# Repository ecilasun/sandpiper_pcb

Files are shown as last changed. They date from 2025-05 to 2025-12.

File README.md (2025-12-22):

## Sandpiper keyboard PCB and enclosure design files

This repo contains the PCB files for sandpiper project.

## Notes

- This PCB is optional and is not required to be able to run sandpiper. It merely contains a custom USB keyboard that fits into the provided enclosure.
- The enclosure is also optional. Sandpiper does not requre an enclosure to function and can be booted from pretty much any Xynq7020 board with 512Mbytes of memory, an etnernet and USB controller, plus some HDMI connector leading to the FPGA pins. For boards with more memory than 512Mbytes the device tree and SDK has to be updated to shift device addresses to the last 32Mbytes of memory. This also means th driver has to be rebuilt with those addresses (in the future driver will read them from the devic tree so there won't be a need to rebuild it)
- The enclosure is designed to be printed in one big piece for the top and bottom halves (plus the side connection pieces) Recommended material is PETG-strong as it is very unlikely to warp. Other materials might also work but print at your own risk or split the design manually, as there's no built-in measures in the design to avoid warping.
- Enclosure design requires solidworks connected, and the pcb design required KiCad 9 or above.
- If you intend to build a PCB yourself via online services (oshpark, jlcpcb etc) please note to match the parts to the ones listed as close as you can. Mismatches in part numbers might result in wrong pin connections.
- If you build the keyboard PCB and want to program the firmware on it, please see the firmware/ folder in this repo. Use an AVR programmer with AVRdude / AVRdudess or QMK Toolbox to burn the flash onto the chip.
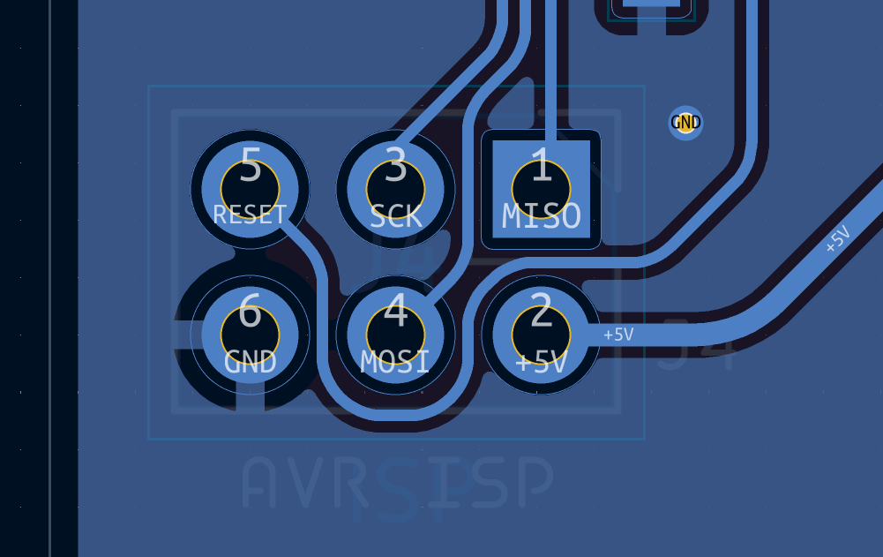
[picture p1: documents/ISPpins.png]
- The pin header for the programmer goes on the bottom side of the board where the chip sits, and the square pin connection is actually the MISO pin and not the ground pin due to an error. Please see the following image to locate the correct pins and plug the programmer header accordingly:<br><br>
- Do not forget to cut or remove the programming header pins once you're done so that the board does not get stuck or bend when sliding it into the rails on the bottom side of the enclosure.

## Documentation

See the [Sandpiper project page](https://ecilasun.github.io/sandpiper/) for links to all related repositories and SDK documentation.

## Development toolchains

See the [Sandpiper project page](https://ecilasun.github.io/sandpiper/) for development toolchain setup instructions.

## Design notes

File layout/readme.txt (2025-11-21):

Please open the attached sandpiper-layout.json file in https://www.keyboard-layout-editor.com/#/ (drag+drop it)

Now download the layout and paste it into the following web site and check that the wiring is correct
https://kbfirmware.com/

(Or if you're in a hurry, I've already provided a premade layout json file here: sandpiperfirmwarelayout.json that you can Upload)

Now you can use the Compile section to generate the firmware to upload to the microcontroller

NOTE: In case of an issue and if the import doesn't work, try to paste the following into the Raw Data tab:

["ESC","!\n1","@\n2","#\n3","$\n4","%\n5","^\n6","&\n7","*\n8","(\n9",")\n0","_\n-","+\n=",{w:2},"Backspace"],
[{w:1.5},"Tab","Q","W","E","R","T","Y","U","I","O","P","{\n[","}\n]",{w:1.5},"|\n\\"],
[{w:1.75},"Caps Lock","A","S","D","F","G","H","J","K","L",":\n;","\"\n'",{w:2.25},"Enter"],
[{x:0.5,w:1.75},"Shift","Z","X","C","V","B","N","M","<\n,",">\n.","?\n/",{w:2.25},"Shift","↑"],
[{x:0.5,w:1.25},"Ctrl","Fn",{w:1.25},"Alt",{x:0.25,a:7,w:6.25},"",{x:0.25,a:4,w:1.25},"Alt","Pause",{x:0.5},"←","↓","→"]

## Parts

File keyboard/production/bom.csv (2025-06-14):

Designator | Footprint | Quantity | Value | LCSC Part #
C1 | 0805 | 1 | 1uF
C2, C3, C4 | 0805 | 3 | 0.1uF
C5 | 0805 | 1 | 10uF
C6, C7 | 0805 | 2 | 22pF
C8 | 0805 | 1 | 100nF
D1, D10, D11, D12, D13, D14, D15, D16, D17, D18, D19, D2, D20, D21, D22, D23, D24, D25, D26, D27, D28, D29, D3, D30, D31, D32, D33, D34, D35, D36, D37, D38, D39, D4, D40, D41, D42, D43, D44, D45, D46, D47, D48, D49, D5, D50, D51, D52, D53, D54, D55, D56, D57, D58, D59, D6, D60, D61, D62, D63, D7, D8, D9 | D_SOD-323_HandSoldering | 63 | 1N4148WS‎
R1, R4 | 0805 | 2 | 10K
R2, R3 | 0805 | 2 | 22R
U1 | TQFP-44_10x10mm_P0.8mm | 1 | ATmega32U4-A
Y1 | Crystal_SMD_3225-4Pin_3.2x2.5mm | 1 | 16MHz

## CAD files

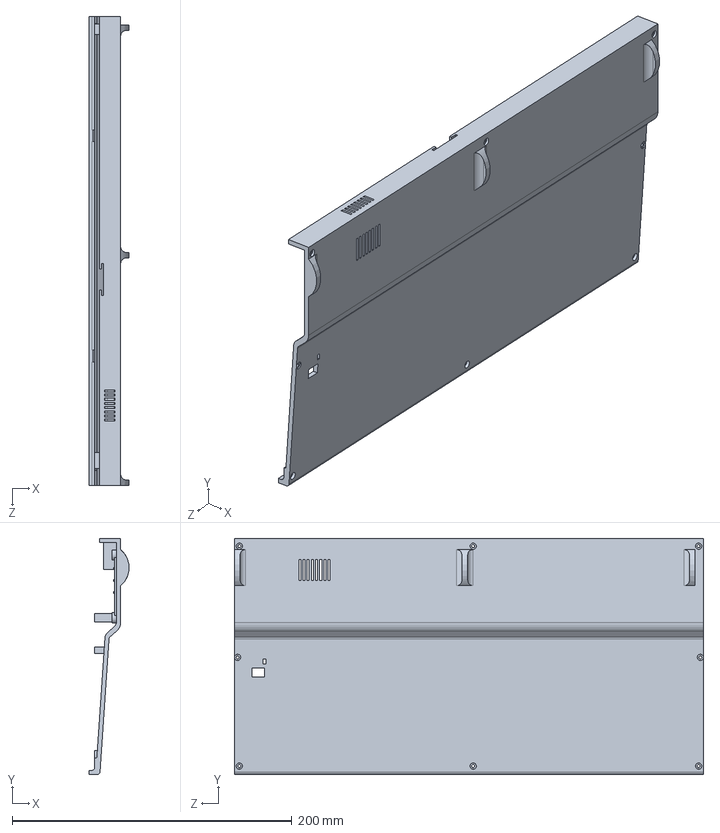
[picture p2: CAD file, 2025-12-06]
enclosure/profile.SLDPRT
28.6 x 168.8 x 335.5 mm

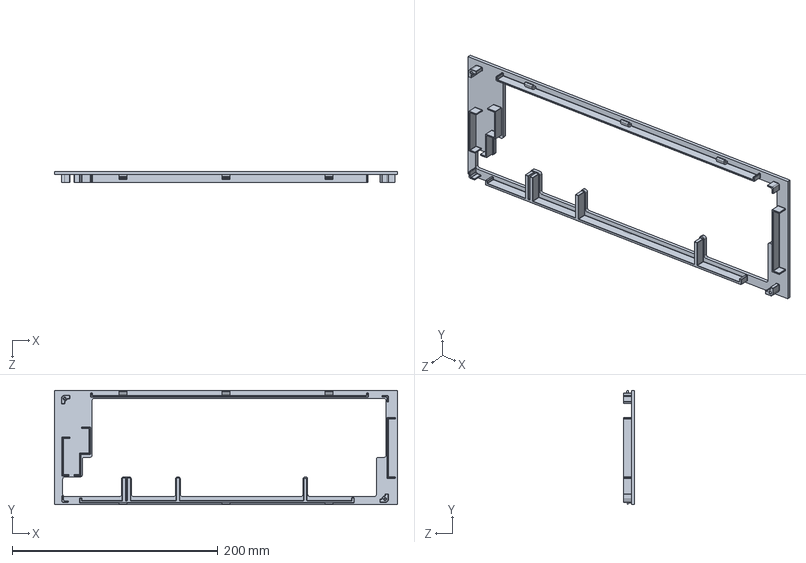
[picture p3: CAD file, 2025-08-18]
enclosure2/faceplate.SLDPRT
333.4 x 111.2 x 11.1 mm

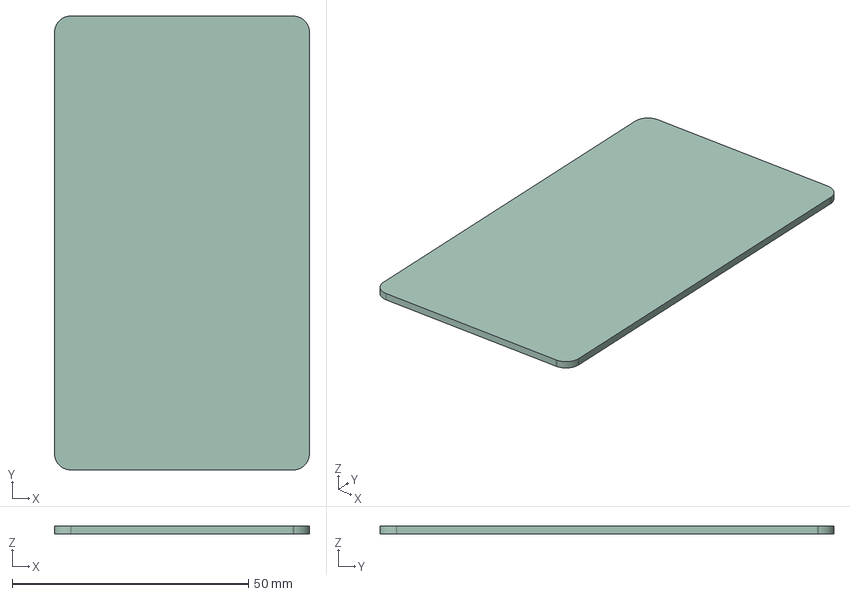
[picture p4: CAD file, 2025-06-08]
fpgamock/fpgamock.step
54.0 x 96.1 x 1.60 mm

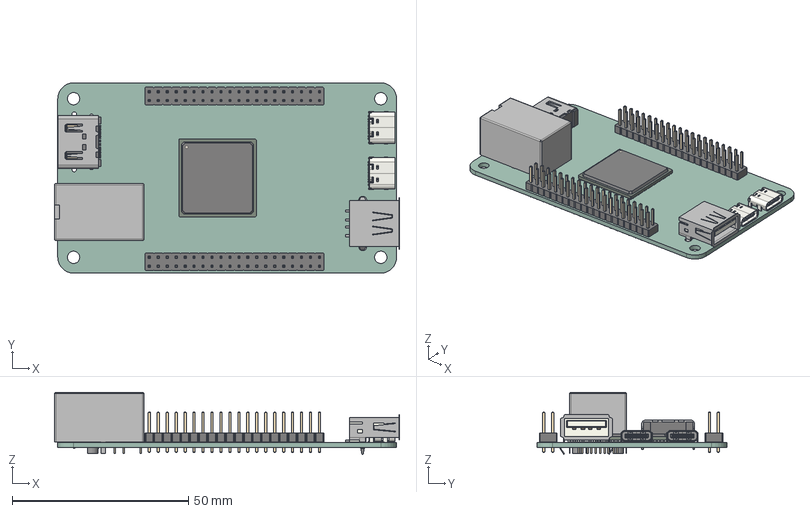
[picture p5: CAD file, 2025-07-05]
keyboard/smartzynqmock.step
97.9 x 54.0 x 17.7 mm
USB_C_Receptacle_GCT_USB4105-xx-A_16P_TopMnt_Horizontal x 2
BGA-484_23.0x23.0mm_Layout22x22_P1.0mm
HDMI_A_Molex_208658-1001_Horizontal
PinHeader_2x20_P2.54mm_Vertical x 2
USB_A_TE_292303-7_Horizontal
RJ45_Molex_9346520x_Horizontal
smartzynqmock_PCB

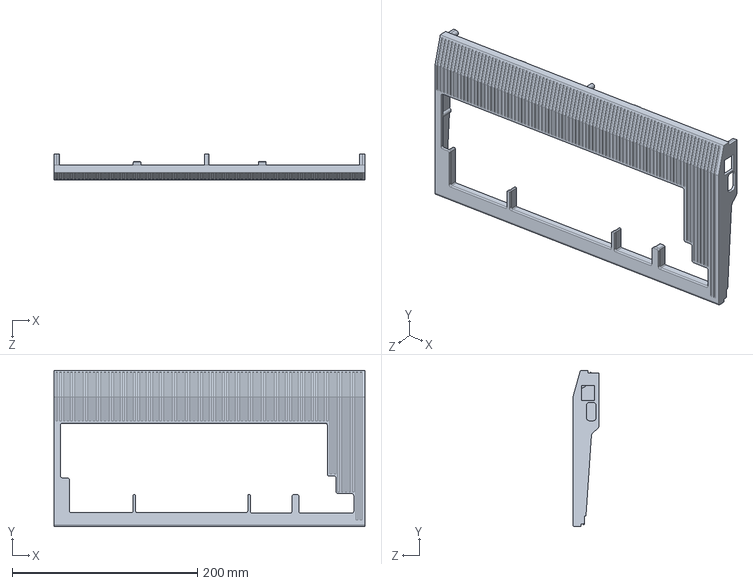
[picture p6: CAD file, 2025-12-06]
enclosure/faceplate.SLDPRT
335.5 x 168.8 x 28.2 mm

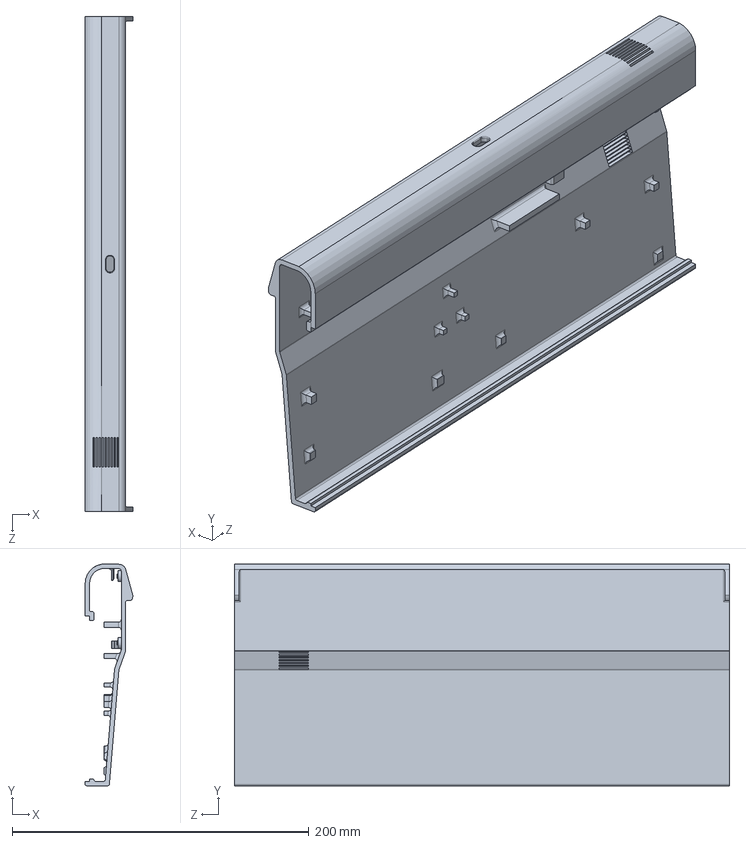
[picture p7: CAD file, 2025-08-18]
enclosure2/bottom.SLDPRT
32.2 x 149.2 x 333.4 mm

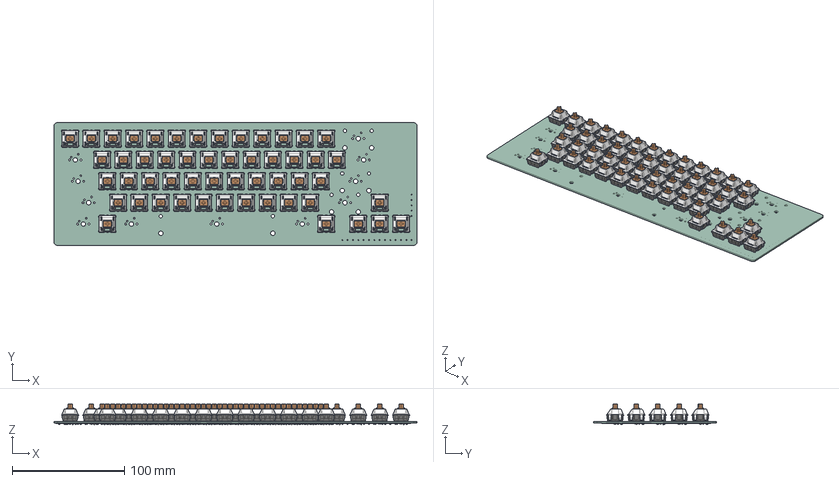
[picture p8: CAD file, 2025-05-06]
keyboard/keyboard.step
323.9 x 109.5 x 18.6 mm
SW_Cherry_MX_PCB_cp x 52
D_SOD_323 x 63
keyboard_PCB

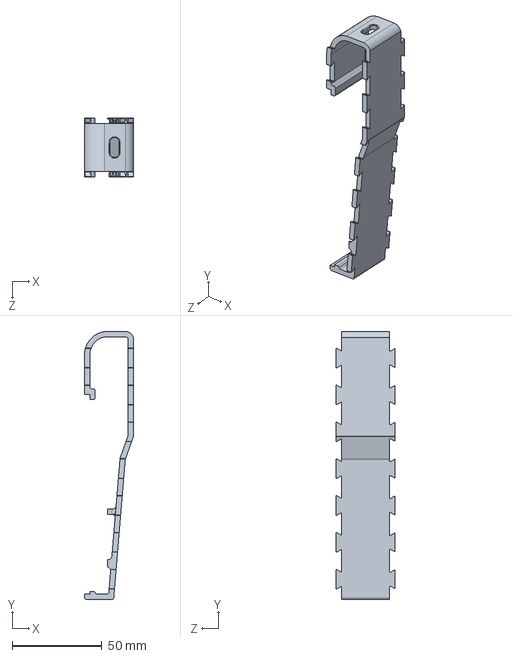
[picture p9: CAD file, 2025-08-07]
enclosure2/bottomcenter.SLDPRT
27.3 x 149.2 x 32.7 mm

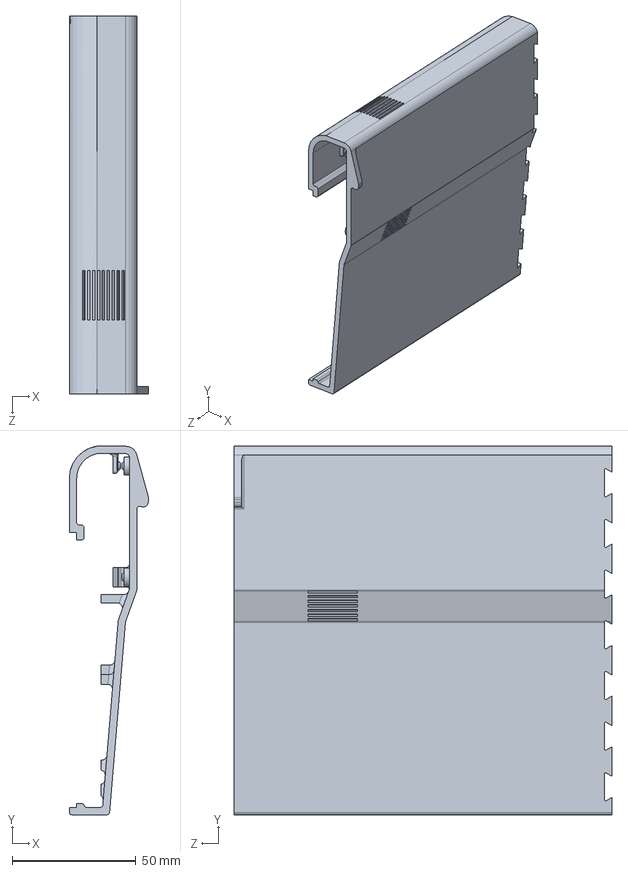
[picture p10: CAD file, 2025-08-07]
enclosure2/bottomright.SLDPRT
32.2 x 149.2 x 153.0 mm

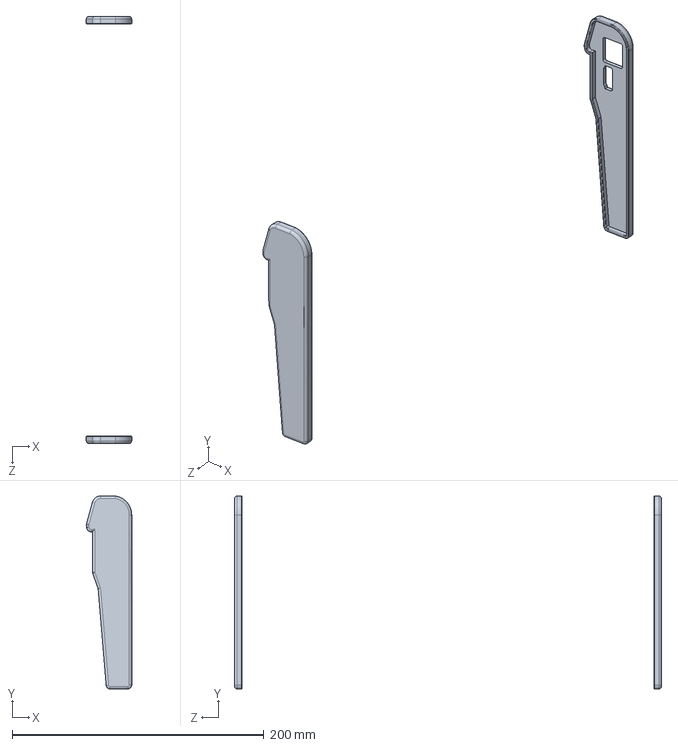
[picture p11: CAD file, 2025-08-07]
enclosure2/sidecovers.SLDPRT
36.1 x 153.2 x 339.1 mm

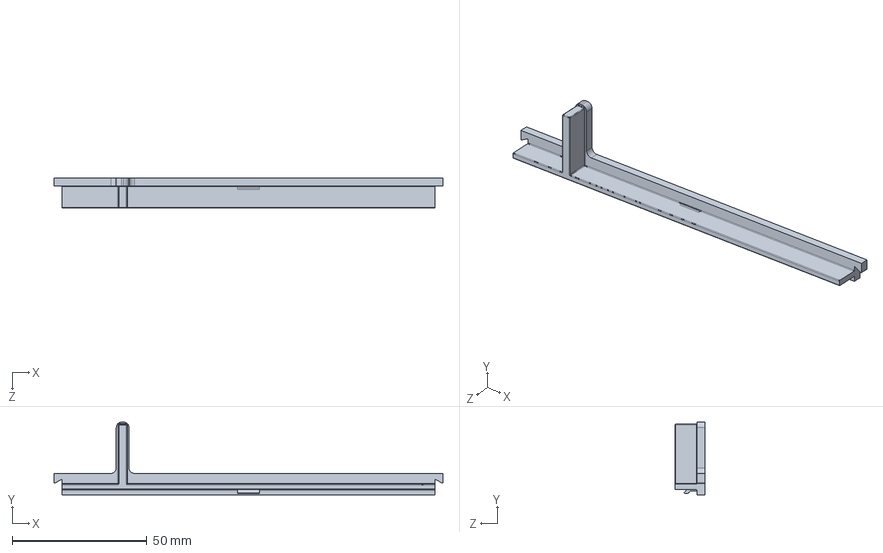
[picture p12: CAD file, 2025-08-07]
enclosure2/platemidbottom.SLDPRT
144.5 x 27.1 x 11.1 mm

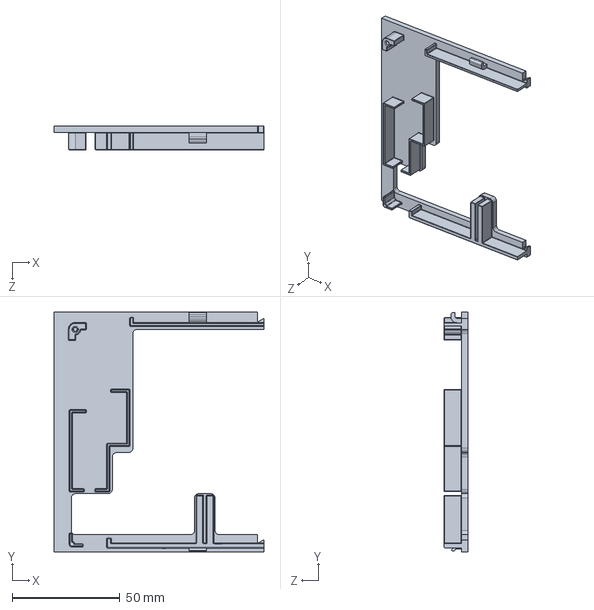
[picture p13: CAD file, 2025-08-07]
enclosure2/plateright.SLDPRT
97.3 x 111.2 x 11.1 mm

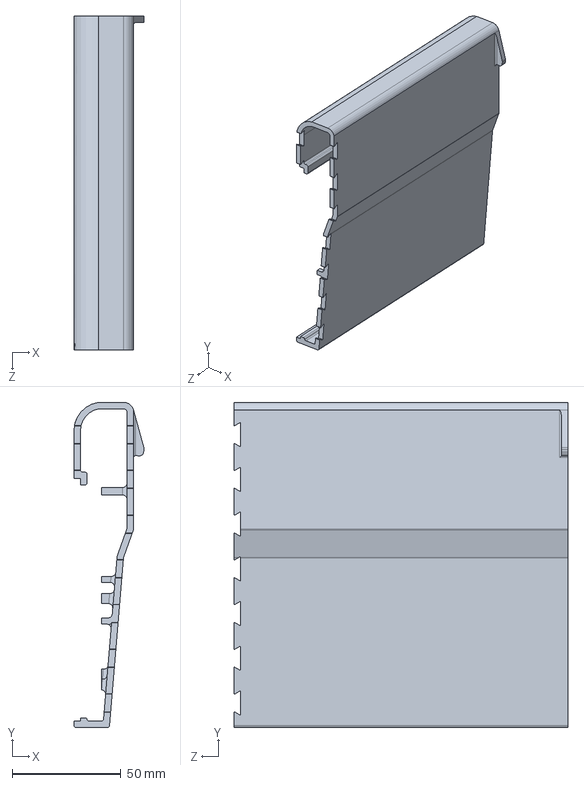
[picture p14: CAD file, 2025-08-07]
enclosure2/bottomleft.SLDPRT
32.2 x 149.2 x 153.2 mm

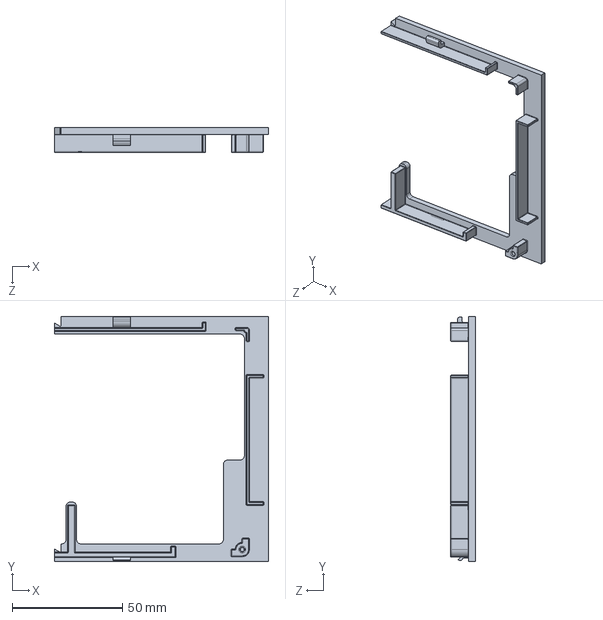
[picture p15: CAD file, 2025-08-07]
enclosure2/plateleft.SLDPRT
97.3 x 111.2 x 11.1 mm

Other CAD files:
keyboard/enclosure/enclosure.SLDASM
enclosure/enclosure.SLDASM
enclosure2/leftbody.SLDPRT
enclosure2/platemidtop.SLDPRT
deprecated/leftbody.SLDPRT
deprecated/platemidtop.SLDPRT
deprecated/platerightSLDPRT.SLDPRT
deprecated/rightbody.SLDPRT
enclosure2/platerightSLDPRT.SLDPRT
enclosure2/rightbody.SLDPRT

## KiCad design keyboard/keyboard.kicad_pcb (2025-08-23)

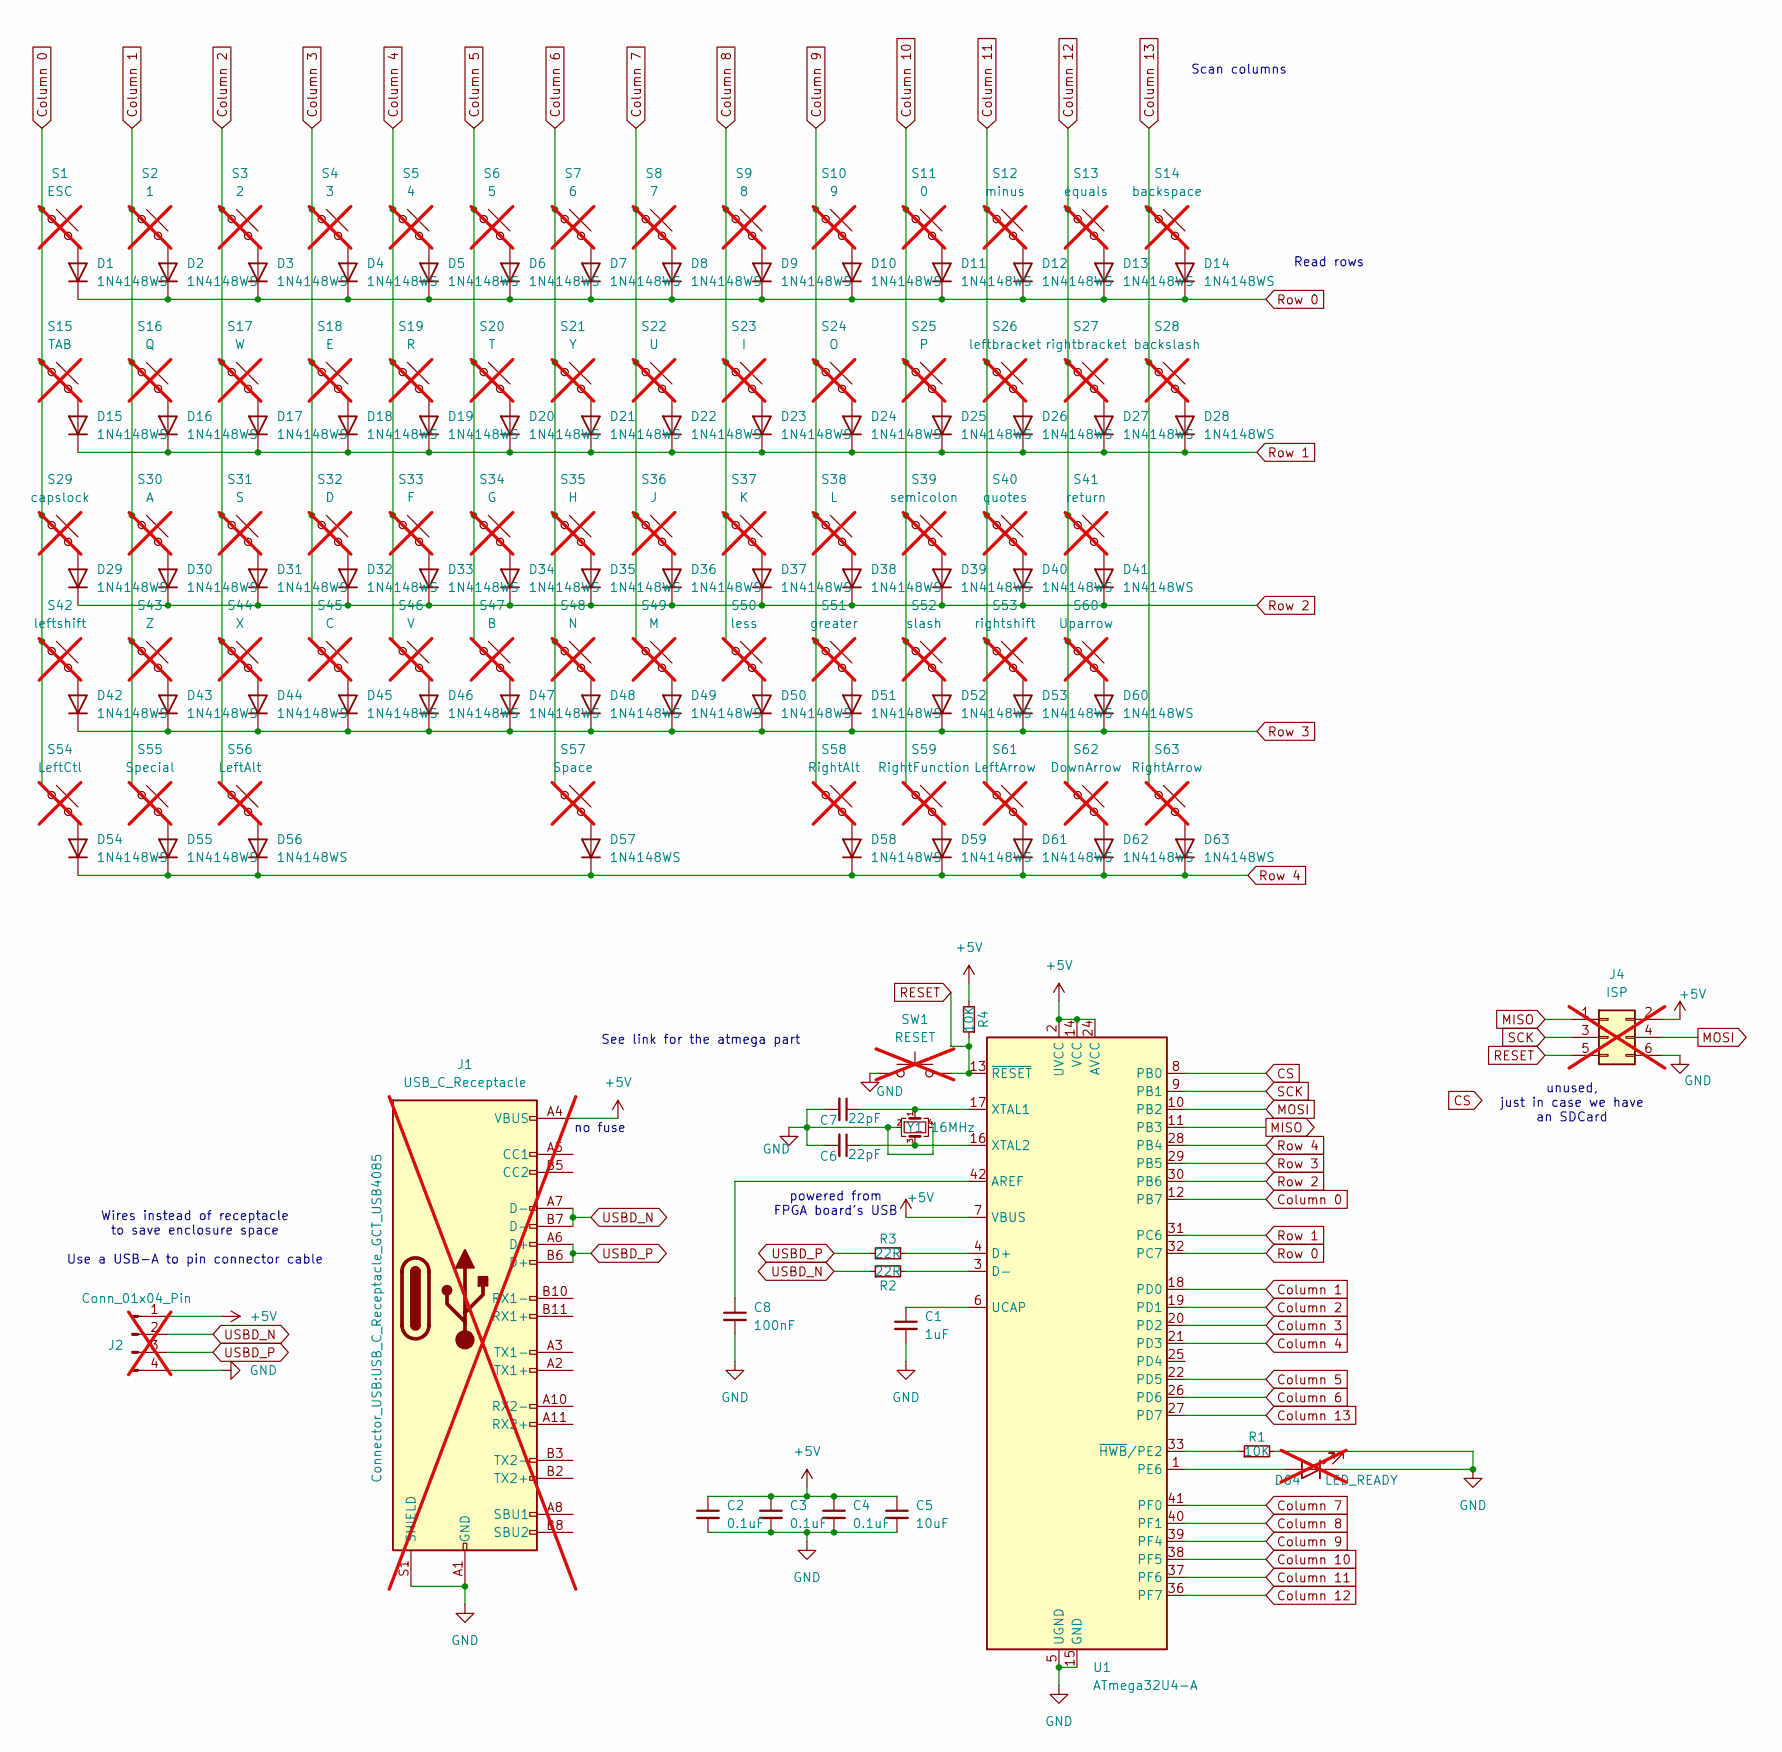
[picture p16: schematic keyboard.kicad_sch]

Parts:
C1: 1uF; C_0805_2012Metric
C2, C3, C4: 0.1uF; C_0805_2012Metric
C5: 10uF; C_0805_2012Metric
C6, C7: 22pF; C_0805_2012Metric
C8: 100nF; C_0805_2012Metric
D1, D2, D3, D4, D5, D6, D7, D8, D9, D10, D11, D12, D13, D14, D15, D16, D17, D18, D19, D20, D21, D22, D23, D24, D25, D26, D27, D28, D29, D30, D31, D32, D33, D34, D35, D36, D37, D38, D39, D40, D41, D42, D43, D44, D45, D46, D47, D48, D49, D50, D51, D52, D53, D54, D55, D56, D57, D58, D59, D60, D61, D62, D63: 1N4148WS‎; D_SOD-323_HandSoldering
D64: LED_READY; LED_1206_3216Metric; not fitted
J1: USB_C_Receptacle; USB_C_Receptacle_GCT_USB4085; not fitted
J2: Conn_01x04_Pin; PinHeader_1x04_P2.54mm_Vertical; not fitted
J4: ISP; PinHeader_2x03_P2.54mm_Vertical; not fitted
R1, R4: 10K; R_0805_2012Metric
R2, R3: 22R; R_0805_2012Metric
S1: ESC; SW_Cherry_MX_1.00u_PCB; not fitted
S2: 1; SW_Cherry_MX_1.00u_PCB; not fitted
S3: 2; SW_Cherry_MX_1.00u_PCB; not fitted
S4: 3; SW_Cherry_MX_1.00u_PCB; not fitted
S5: 4; SW_Cherry_MX_1.00u_PCB; not fitted
S6: 5; SW_Cherry_MX_1.00u_PCB; not fitted
S7: 6; SW_Cherry_MX_1.00u_PCB; not fitted
S8: 7; SW_Cherry_MX_1.00u_PCB; not fitted
S9: 8; SW_Cherry_MX_1.00u_PCB; not fitted
S10: 9; SW_Cherry_MX_1.00u_PCB; not fitted
S11: 0; SW_Cherry_MX_1.00u_PCB; not fitted
S12: minus; SW_Cherry_MX_1.00u_PCB; not fitted
S13: equals; SW_Cherry_MX_1.00u_PCB; not fitted
S14: backspace; SW_Cherry_MX_2.00u_PCB; not fitted
S15: TAB; SW_Cherry_MX_1.00u_PCB; not fitted
S16: Q; SW_Cherry_MX_1.00u_PCB; not fitted
S17: W; SW_Cherry_MX_1.00u_PCB; not fitted
S18: E; SW_Cherry_MX_1.00u_PCB; not fitted
S19: R; SW_Cherry_MX_1.00u_PCB; not fitted
S20: T; SW_Cherry_MX_1.00u_PCB; not fitted
S21: Y; SW_Cherry_MX_1.00u_PCB; not fitted
S22: U; SW_Cherry_MX_1.00u_PCB; not fitted
S23: I; SW_Cherry_MX_1.00u_PCB; not fitted
S24: O; SW_Cherry_MX_1.00u_PCB; not fitted
S25: P; SW_Cherry_MX_1.00u_PCB; not fitted
S26: leftbracket; SW_Cherry_MX_1.00u_PCB; not fitted
S27: rightbracket; SW_Cherry_MX_1.00u_PCB; not fitted
S28: backslash; SW_Cherry_MX_1.00u_PCB; not fitted
S29: capslock; SW_Cherry_MX_1.00u_PCB; not fitted
S30: A; SW_Cherry_MX_1.00u_PCB; not fitted
S31: S; SW_Cherry_MX_1.00u_PCB; not fitted
S32: D; SW_Cherry_MX_1.00u_PCB; not fitted
S33: F; SW_Cherry_MX_1.00u_PCB; not fitted
S34: G; SW_Cherry_MX_1.00u_PCB; not fitted
S35: H; SW_Cherry_MX_1.00u_PCB; not fitted
S36: J; SW_Cherry_MX_1.00u_PCB; not fitted
S37: K; SW_Cherry_MX_1.00u_PCB; not fitted
S38: L; SW_Cherry_MX_1.00u_PCB; not fitted
S39: semicolon; SW_Cherry_MX_1.00u_PCB; not fitted
S40: quotes; SW_Cherry_MX_1.00u_PCB; not fitted
S41: return; SW_Cherry_MX_2.25u_PCB; not fitted
S42: leftshift; SW_Cherry_MX_1.75u_PCB; not fitted
S43: Z; SW_Cherry_MX_1.00u_PCB; not fitted
S44: X; SW_Cherry_MX_1.00u_PCB; not fitted
S45: C; SW_Cherry_MX_1.00u_PCB; not fitted
S46: V; SW_Cherry_MX_1.00u_PCB; not fitted
S47: B; SW_Cherry_MX_1.00u_PCB; not fitted
S48: N; SW_Cherry_MX_1.00u_PCB; not fitted
S49: M; SW_Cherry_MX_1.00u_PCB; not fitted
S50: less; SW_Cherry_MX_1.00u_PCB; not fitted
S51: greater; SW_Cherry_MX_1.00u_PCB; not fitted
S52: slash; SW_Cherry_MX_1.00u_PCB; not fitted
S53: rightshift; SW_Cherry_MX_2.25u_PCB; not fitted
S54: LeftCtl; SW_Cherry_MX_1.25u_PCB; not fitted
S55: Special; SW_Cherry_MX_1.00u_PCB; not fitted
S56: LeftAlt; SW_Cherry_MX_1.25u_PCB; not fitted
S57: Space; SW_Cherry_MX_6.25u_PCB; not fitted
S58: RightAlt; SW_Cherry_MX_1.25u_PCB; not fitted
S59: RightFunction; SW_Cherry_MX_1.00u_PCB; not fitted
S60: Uparrow; SW_Cherry_MX_1.00u_PCB; not fitted
S61: LeftArrow; SW_Cherry_MX_1.00u_PCB; not fitted
S62: DownArrow; SW_Cherry_MX_1.00u_PCB; not fitted
S63: RightArrow; SW_Cherry_MX_1.00u_PCB; not fitted
SW1: RESET; SW_Tactile_SPST_NO_Straight_CK_PTS636Sx25SMTRLFS; not fitted
U1: ATmega32U4-A; TQFP-44_10x10mm_P0.8mm
Y1: 16MHz; Crystal_SMD_3225-4Pin_3.2x2.5mm

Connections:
+5V: C2.1, C3.1, C4.1, C5.1, J1.A4 (VBUS), J1.A9 (VBUS), J1.B4 (VBUS), J1.B9 (VBUS), J2.1, J4.2, R4.2, U1.2 (UVCC), U1.7 (VBUS), U1.14 (VCC), U1.24 (AVCC), U1.34 (VCC), U1.44 (AVCC)
CS: U1.8 (PB0)
Column 0: S1.1, S15.1, S29.1, S42.1, S54.1, U1.12 (PB7)
Column 1: S2.1, S16.1, S30.1, S43.1, S55.1, U1.18 (PD0)
Column 2: S3.1, S17.1, S31.1, S44.1, S56.1, U1.19 (PD1)
Column 3: S4.1, S18.1, S32.1, S45.1, U1.20 (PD2)
Column 4: S5.1, S19.1, S33.1, S46.1, U1.21 (PD3)
Column 5: S6.1, S20.1, S34.1, S47.1, U1.22 (PD5)
Column 6: S7.1, S21.1, S35.1, S48.1, S57.1, U1.26 (PD6)
Column 7: S8.1, S22.1, S36.1, S49.1, U1.41 (PF0)
Column 8: S9.1, S23.1, S37.1, S50.1, U1.40 (PF1)
Column 9: S10.1, S24.1, S38.1, S51.1, S58.1, U1.39 (PF4)
Column 10: S11.1, S25.1, S39.1, S52.1, S59.1, U1.38 (PF5)
Column 11: S12.1, S26.1, S40.1, S53.1, S61.1, U1.37 (PF6)
Column 12: S13.1, S27.1, S41.1, S60.1, S62.1, U1.36 (PF7)
Column 13: S14.1, S28.1, S63.1, U1.27 (PD7)
GND: C1.2, C2.2, C3.2, C4.2, C5.2, C6.2, C7.2, C8.2, D64.1 (K), J1.A1 (GND), J1.A12 (GND), J1.B1 (GND), J1.B12 (GND), J1.S1 (SHIELD), J2.4, J4.6, R1.2, SW1.1, U1.5 (UGND), U1.15 (GND), U1.23 (GND), U1.35 (GND), U1.43 (GND), Y1.2, Y1.4
MISO: J4.1, U1.11 (PB3)
MOSI: J4.4, U1.10 (PB2)
unnamed: D1.2 (A), S1.2
unnamed: D2.2 (A), S2.2
unnamed: D3.2 (A), S3.2
unnamed: D4.2 (A), S4.2
unnamed: D5.2 (A), S5.2
unnamed: D6.2 (A), S6.2
unnamed: D7.2 (A), S7.2
unnamed: D8.2 (A), S8.2
unnamed: D9.2 (A), S9.2
unnamed: D10.2 (A), S10.2
unnamed: D11.2 (A), S11.2
unnamed: D12.2 (A), S12.2
unnamed: D13.2 (A), S13.2
unnamed: D14.2 (A), S14.2
unnamed: D15.2 (A), S15.2
unnamed: D16.2 (A), S16.2
unnamed: D17.2 (A), S17.2
unnamed: D18.2 (A), S18.2
unnamed: D19.2 (A), S19.2
unnamed: D20.2 (A), S20.2
unnamed: D21.2 (A), S21.2
unnamed: D22.2 (A), S22.2
unnamed: D23.2 (A), S23.2
unnamed: D24.2 (A), S24.2
unnamed: D25.2 (A), S25.2
unnamed: D26.2 (A), S26.2
unnamed: D27.2 (A), S27.2
unnamed: D28.2 (A), S28.2
unnamed: D29.2 (A), S29.2
unnamed: D30.2 (A), S30.2
unnamed: D31.2 (A), S31.2
unnamed: D32.2 (A), S32.2
unnamed: D33.2 (A), S33.2
unnamed: D34.2 (A), S34.2
unnamed: D35.2 (A), S35.2
unnamed: D36.2 (A), S36.2
unnamed: D37.2 (A), S37.2
unnamed: D38.2 (A), S38.2
unnamed: D39.2 (A), S39.2
unnamed: D40.2 (A), S40.2
unnamed: D41.2 (A), S41.2
unnamed: D42.2 (A), S42.2
unnamed: D43.2 (A), S43.2
unnamed: D44.2 (A), S44.2
unnamed: D45.2 (A), S45.2
unnamed: D46.2 (A), S46.2
unnamed: D47.2 (A), S47.2
unnamed: D48.2 (A), S48.2
unnamed: D49.2 (A), S49.2
unnamed: D50.2 (A), S50.2
unnamed: D51.2 (A), S51.2
unnamed: D52.2 (A), S52.2
unnamed: D53.2 (A), S53.2
unnamed: D54.2 (A), S54.2
unnamed: D55.2 (A), S55.2
unnamed: D56.2 (A), S56.2
unnamed: D57.2 (A), S57.2
unnamed: D58.2 (A), S58.2
unnamed: D59.2 (A), S59.2
unnamed: D60.2 (A), S60.2
unnamed: D61.2 (A), S61.2
unnamed: D62.2 (A), S62.2
unnamed: D63.2 (A), S63.2
unnamed: D64.2 (A), U1.1 (PE6)
unnamed: C8.1, U1.42 (AREF)
unnamed: R3.1, U1.4 (D+)
unnamed: R2.2, U1.3 (D-)
unnamed: C1.1, U1.6 (UCAP)
unnamed: C7.1, U1.17 (XTAL1), Y1.1
unnamed: C6.1, U1.16 (XTAL2), Y1.3
unnamed: R1.1, U1.33 (~HWB/PE2)
RESET: J4.5, R4.1, SW1.2, U1.13 (~RESET)
Row 0: D1.1 (K), D2.1 (K), D3.1 (K), D4.1 (K), D5.1 (K), D6.1 (K), D7.1 (K), D8.1 (K), D9.1 (K), D10.1 (K), D11.1 (K), D12.1 (K), D13.1 (K), D14.1 (K), U1.32 (PC7)
Row 1: D15.1 (K), D16.1 (K), D17.1 (K), D18.1 (K), D19.1 (K), D20.1 (K), D21.1 (K), D22.1 (K), D23.1 (K), D24.1 (K), D25.1 (K), D26.1 (K), D27.1 (K), D28.1 (K), U1.31 (PC6)
Row 2: D29.1 (K), D30.1 (K), D31.1 (K), D32.1 (K), D33.1 (K), D34.1 (K), D35.1 (K), D36.1 (K), D37.1 (K), D38.1 (K), D39.1 (K), D40.1 (K), D41.1 (K), U1.30 (PB6)
Row 3: D42.1 (K), D43.1 (K), D44.1 (K), D45.1 (K), D46.1 (K), D47.1 (K), D48.1 (K), D49.1 (K), D50.1 (K), D51.1 (K), D52.1 (K), D53.1 (K), D60.1 (K), U1.29 (PB5)
Row 4: D54.1 (K), D55.1 (K), D56.1 (K), D57.1 (K), D58.1 (K), D59.1 (K), D61.1 (K), D62.1 (K), D63.1 (K), U1.28 (PB4)
SCK: J4.3, U1.9 (PB1)
USBD_N: J1.A7 (D-), J1.B7 (D-), J2.2, R2.1
USBD_P: J1.A6 (D+), J1.B6 (D+), J2.3, R3.2

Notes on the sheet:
Scan columns
no fuse
unused, just in case we have an SDCard
Wires instead of receptacle to save enclosure space Use a USB-A to pin connector cable
See link for the atmega part
powered from FPGA board's USB
Read rows

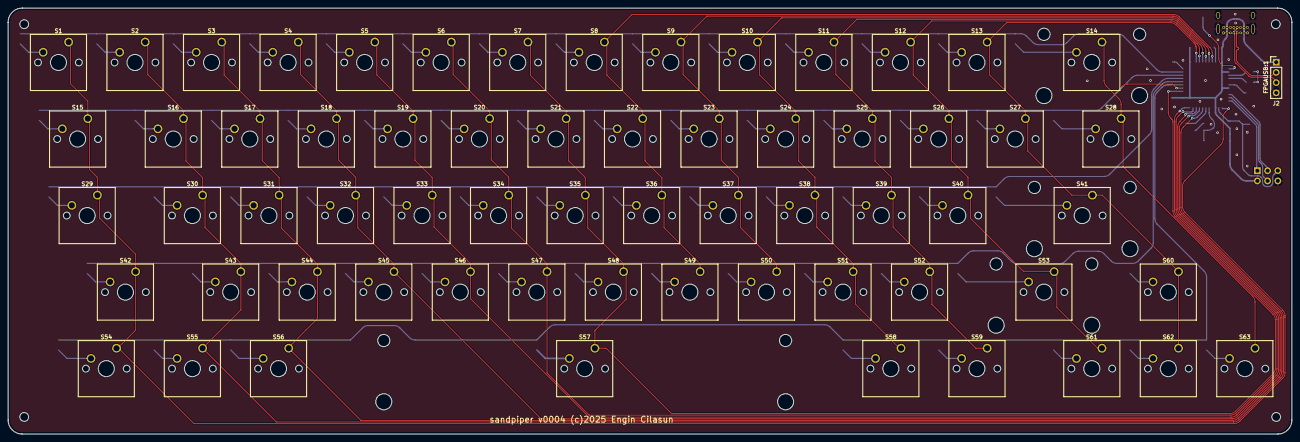
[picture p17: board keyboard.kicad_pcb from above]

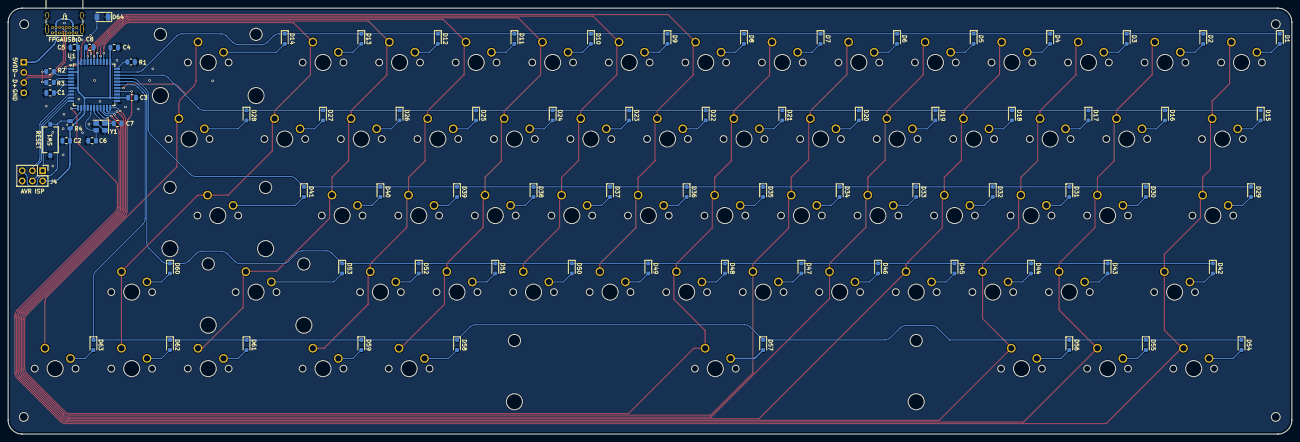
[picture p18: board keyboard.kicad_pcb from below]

Board: 2 copper layers, 319.5 x 106.0 mm, 145 parts (81 on the bottom side), 98 nets.

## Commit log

2025-05-06 initial submit
    [bom.csv, designators.csv, keyboard.kicad_pcb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]
2025-05-06 Updated with reference switches
    [keyboard.kicad_pcb, keyboard.kicad_sch, keyboard.step]
2025-05-06 Updated mechanical bits
    [keyboard.SLDASM, keyboard.kicad_pcb]
2025-05-29 USB keyboard instead
    [bom.csv, designators.csv, enclosure.SLDASM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]
2025-06-01 updated pcb and enclosure
    [keyboard.kicad_pcb]
2025-06-05 Updated keyboard with fixes, also much smaller
    [bom.csv, designators.csv, keyboard.kicad_pcb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]
2025-06-08 Updated enclousre
    [fpgamock.kicad_pcb, fpgamock.kicad_sch, fpgamock.step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]
2025-06-09 Added default firmware and layout for keyboard
    [Part1.SLDPRT, keyboard.kicad_pcb, keyboardbottom.SLDPRT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]
2025-06-10 Updated keyboard layout and firmware Typing this from the new keyboard :)
    [keyboard.kicad_sch]
2025-06-10 More fixes to the keyboard pcb
    [keyboard.kicad_pcb, keyboard.kicad_sch]
2025-06-14 Updated PCB layout, added caps
    [bom.csv, designators.csv, keyboard.kicad_pcb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]
2025-06-19 PCB update
    [keyboard.kicad_sch]
2025-06-24 More compact enclosure
    [Part1.SLDPRT, bottompart.SLDPRT, fpga_pcb.SLDPRT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]
2025-06-28 Updatd enclosure
    [bottompart.SLDPRT, fpga_pcb.SLDPRT, toppart.SLDPRT]
2025-06-28 More updates to the enclousre
    [bottompart.SLDPRT, fpga_pcb.SLDPRT, toppart.SLDPRT]
2025-07-05 Updated enclosure
    [bottompart.SLDPRT, fpga_pcb.SLDPRT, smartzynqmock.step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]
2025-08-03 Added a smaller enclosure option
    [bottom.SLDPRT, bottom.STL, bottompart.SLDPRT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]
2025-08-06 New enclosure work
    [bottom.SLDPRT, bottomcenter.SLDPRT, bottomleft.SLDPRT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]
2025-08-07 Enclosure 2 fixes
    [bottom.SLDPRT, bottom.STL, bottomcenter.SLDPRT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]
2025-08-10 Removed old enclosure
    [bottom.SLDPRT, bottompart.SLDPRT, fpga_pcb.SLDPRT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]
2025-08-18 New enclousre and fix for PCB
    [bottom.SLDPRT, designators.csv, faceplate.SLDPRT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]
2025-08-23 enclosure and pcb fixes
    [faceplate.SLDPRT, keyboard.kicad_pcb, profile.SLDPRT]
2025-08-30 Minor touchup
    [faceplate.SLDPRT, profile.SLDPRT]
2025-08-30 Tidy up
    [bottom.SLDPRT, bottomcenter.SLDPRT, bottomleft.SLDPRT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]
2025-09-05 Updates to enclosure (snap hooks and detail fixes)
    [faceplate.SLDPRT, profile.SLDPRT]
2025-10-17 Enclosure update
    [faceplate.SLDPRT, profile.SLDPRT]
2025-11-28 Updates to enclosure design
    [enclosure.SLDASM, faceplate.SLDPRT, profile.SLDPRT]
2025-11-29 Update for cable
    [enclosure.SLDASM, faceplate.SLDPRT]
2025-12-06 Enclosure updates
    [enclosure.SLDASM, faceplate.SLDPRT, profile.SLDPRT]

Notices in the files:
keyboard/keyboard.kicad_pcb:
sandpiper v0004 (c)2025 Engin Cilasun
